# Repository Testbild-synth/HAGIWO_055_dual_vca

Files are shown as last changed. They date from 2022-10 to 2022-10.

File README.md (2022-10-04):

# Hagiwo Eurorack Dual Lin-Exp VCA
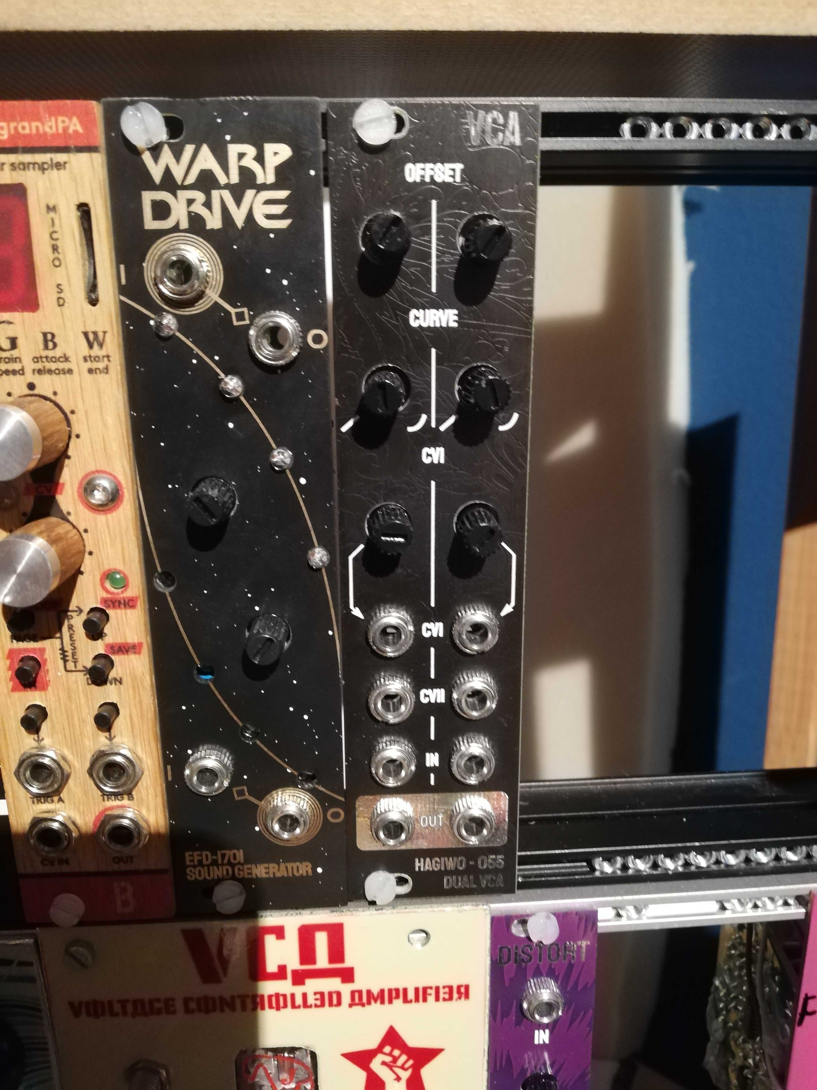
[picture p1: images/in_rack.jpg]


This project is a through hole PCB version the HAGIWO 055 dual veils-style VCA. I added a second CV in. 

## STATUS: CONFIRMED WORKING

## Hardware and PCB
this had to be 2 PCBs and 8HP (its hard to make it smaller without making it SMT), but I think i managed to get it very tidy.

You can find the schematic and BOM in the root folder. 
As mentioned, the module has one circuit PCB and one panel PCB. 

You can order them on any common PCB manufacturing service, I used JLCPCB. For the circuit PCB, standard settings should be fine.
For the panel, since it has copper exposed, make sure to choose a lead free surface finish (LeadFree HASL, ENIG) and/or spraypaint your panels so that you don't get lead on your hands.

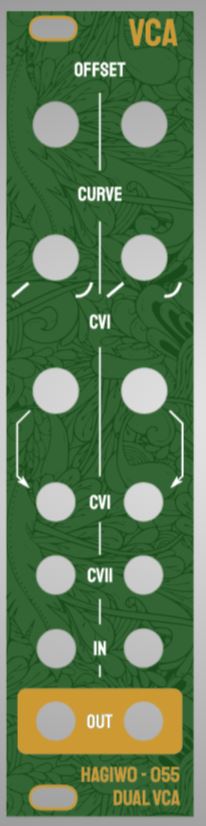
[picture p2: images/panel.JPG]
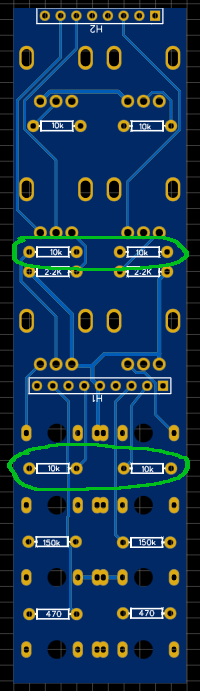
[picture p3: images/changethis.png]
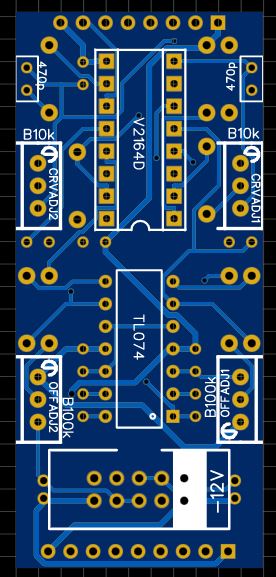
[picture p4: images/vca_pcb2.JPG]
  

Assembly is fairly straight forward, just use the componentent values.
The VCA is built for ~5V cv interval, if you with to use a bigger interval, try replacing the circled 10K resistors with different values.

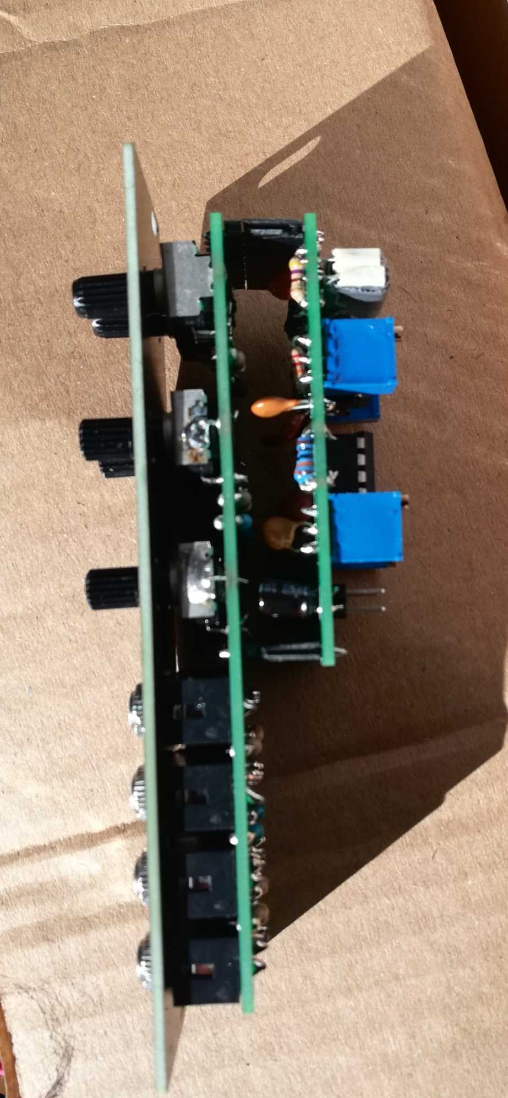
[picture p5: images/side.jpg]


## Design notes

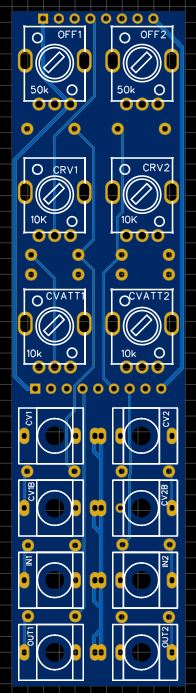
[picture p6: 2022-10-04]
images/vca_pcb1.JPG

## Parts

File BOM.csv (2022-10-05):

Name | Designator | Footprint | Quantity
100p capacitor | C1,C4,C6,C7 | RAD-0.1 | 4
100n capacitor | C2,C3,C10,C12 | RAD-0.1 | 4
470p capacitor | C5,C8 | RAD-0.1 | 2
10uF electrolytic capacitor | C9,C11 | CAP-TH_BD5.0-P2.00-D0.8-FD | 2
B10K Potentiometer R09 | CRV1,CRV2 | R09-5KΩ | 2
B10k Trimpot | CRVADJ1,CRVADJ2 | TRIMPOT-ELETROCURSOS-FOOTPRINT | 2
B100k Trimpot | OFFADJ1,OFFADJ2 | TRIMPOT-ELETROCURSOS-FOOTPRINT | 2
10k Potentiometer R09 | CVATT1,CVATT2 | R09-5KΩ | 2
B50k Potentiometer R09 | OFF1,OFF2 | R09-5KΩ | 2
2.54MM header (male and female) 1x9 | H1 | HDR-F-2.54_1X9 | 1
2.54MM header (male and female) 1x8 | H2 | HDR-F-2.54_1X8 | 1
CV1, CV2, CV1B, CV2B, IN1, IN2, OUT1, OUT2 | J1-J8 | THONKICONN_1 | 8
Eurorack power header/2x5 header | P1 | EURORACK SHROUDED POWER 10 PIN | 1
10k resistor | R1,R2,R3,R11,R12,R13 | R_AXIAL-0.3 | 6
2.2K resistor | R4,R14 | R_AXIAL-0.3 | 2
100k resistor | R5,R15 | R_AXIAL-0.3 | 2
33k resistor | R6,R16 | R_AXIAL-0.3 | 2
150k resistor | R7,R17 | R_AXIAL-0.3 | 2
470 resistor | R8,R9,R18,R19 | R_AXIAL-0.3 | 4
22k resistor | R10,R20 | R_AXIAL-0.3 | 2
7.5k resistor | R21 | R_AXIAL-0.3 | 1
TL074CJ | U1 | DIP14 | 1
V2164D | U2 | V2164D | 1

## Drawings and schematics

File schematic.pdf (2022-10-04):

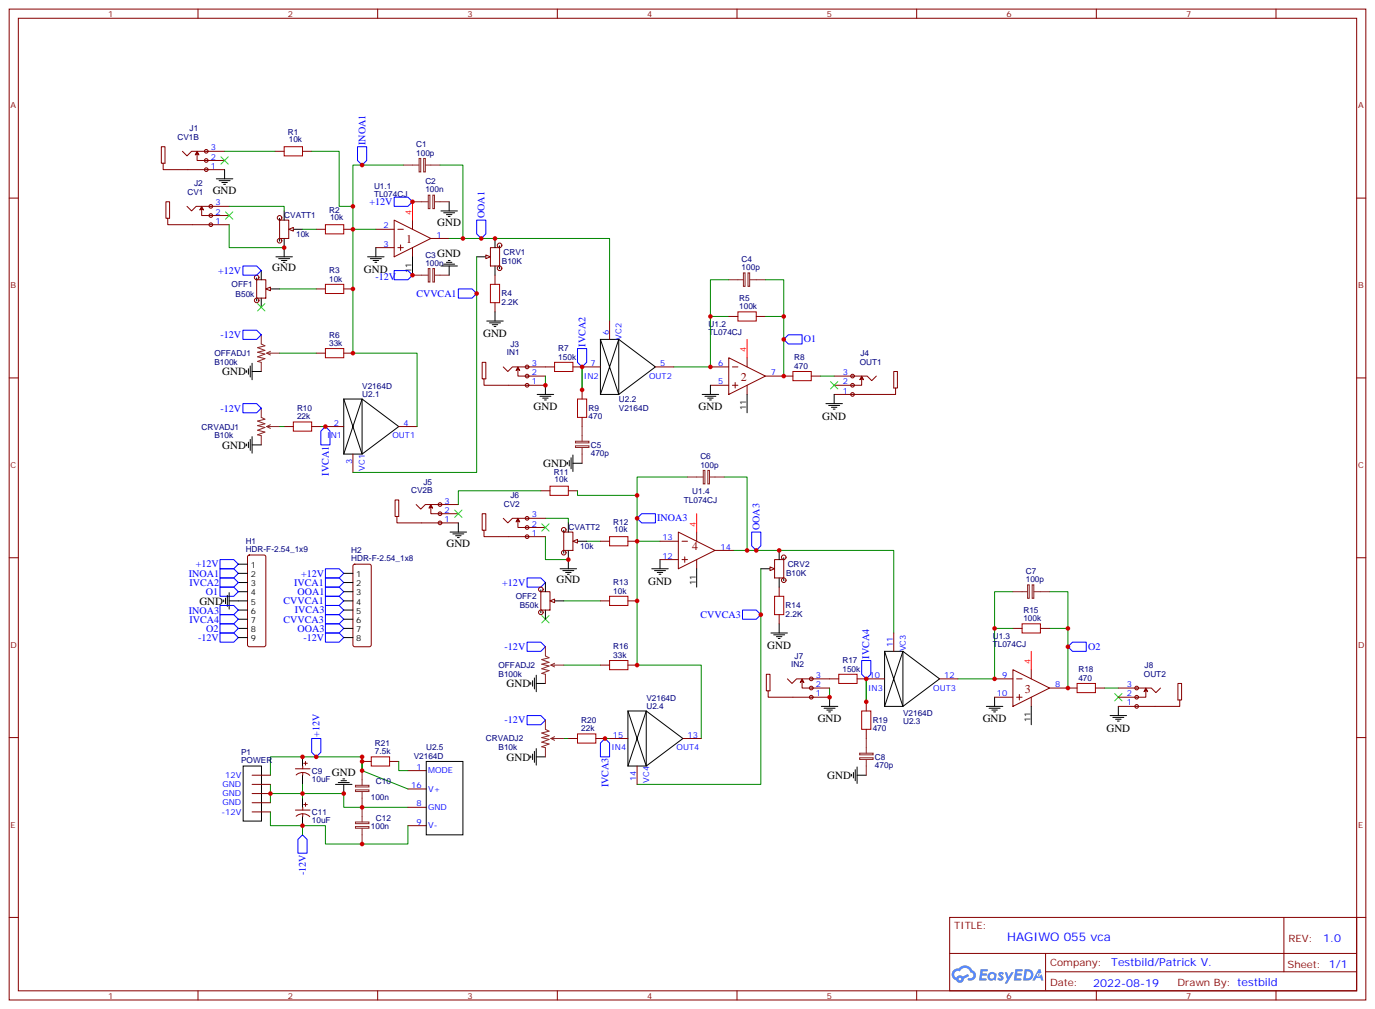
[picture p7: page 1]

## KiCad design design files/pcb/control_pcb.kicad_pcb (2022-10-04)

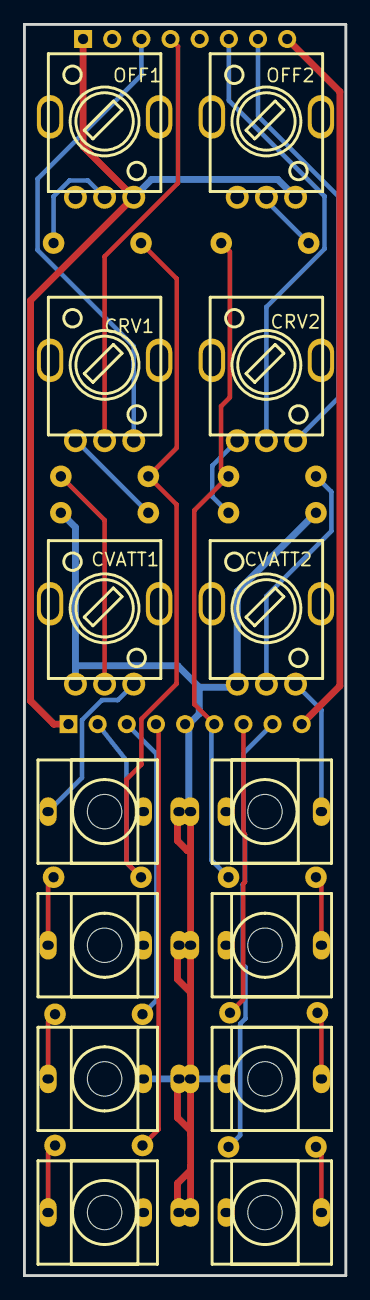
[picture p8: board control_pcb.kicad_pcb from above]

Board: 2 copper layers, 28.0 x 109.0 mm, 28 parts (0 on the bottom side), 27 nets.

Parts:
CRV1, CRV2: 10K; R09-5KΩ
CVATT1, CVATT2: 10k; R09-5KΩ
H1: HDR-F-2.54_1x9; HDR-F-2.54_1X9
H2: HDR-F-2.54_1x8; HDR-F-2.54_1X8
J1: CV1B; THONKICONN_1
J2: CV1; THONKICONN_1
J3: IN1; THONKICONN_1
J4: OUT1; THONKICONN_1
J5: CV2B; THONKICONN_1
J6: CV2; THONKICONN_1
J7: IN2; THONKICONN_1
J8: OUT2; THONKICONN_1
OFF1, OFF2: 50k; R09-5KΩ
R1, R2, R3, R11, R12, R13: 10k; R_AXIAL-0.3
R4, R14: 2.2K; R_AXIAL-0.3
R7, R17: 150k; R_AXIAL-0.3
R8, R18: 470; R_AXIAL-0.3

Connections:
+12V: H1.1, H2.1, OFF1.3, OFF2.3
-12V: H1.9, H2.8
CRV1_1: CRV1.1, R4.2
CVATT1_2: CVATT1.2, R2.1
CVATT2_3: CVATT2.3, J6.3
CVVCA1: CRV1.2, H2.4
CVVCA3: CRV2.2, H2.6
GND: CVATT1.1, CVATT2.1, H1.5, J1.1, J2.1, J3.1, J3.2, J4.1, J5.1, J6.1, J7.1, J7.2, J8.1, R4.1, R14.1
INOA1: H1.2, R1.2, R2.2, R3.2
INOA3: H1.6, R11.2, R12.2, R13.2
IVCA2: H1.3, R7.1
IVCA4: H1.7, R17.1
J1_3: J1.3, R1.1
J2_3: CVATT1.3, J2.3
J3_3: J3.3, R7.2
J5_3: J5.3, R11.1
J8_3: J8.3, R18.1
O1: H1.4, R8.2
O2: H1.8, R18.2
OFF1_2: OFF1.2, R3.1
OOA1: CRV1.3, H2.3
OOA3: CRV2.3, H2.7
R8_1: J4.3, R8.1
R12_1: CVATT2.2, R12.1
R13_1: OFF2.2, R13.1
R14_2: CRV2.1, R14.2
R17_2: J7.3, R17.2

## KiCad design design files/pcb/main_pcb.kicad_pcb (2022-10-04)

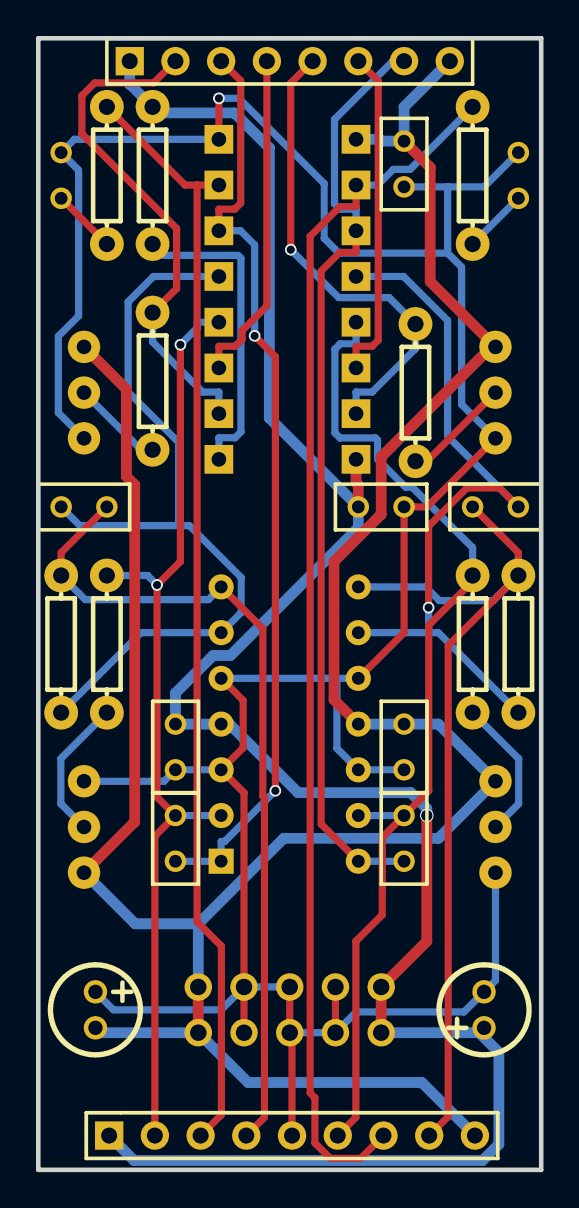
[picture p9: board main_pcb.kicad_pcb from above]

Board: 2 copper layers, 27.9 x 62.9 mm, 30 parts (0 on the bottom side), 24 nets.

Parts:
C1, C4, C6, C7: 100p; RAD-0.1
C2, C3, C10, C12: 100n; RAD-0.1
C5, C8: 470p; RAD-0.1
C9, C11: 10uF; CAP-TH_BD5.0-P2.00-D0.8-FD
CRVADJ1, CRVADJ2: B10k; TRIMPOT-ELETROCURSOS-FOOTPRINT
H1: HDR-F-2.54_1x9; HDR-F-2.54_1X9
H2: HDR-F-2.54_1x8; HDR-F-2.54_1X8
OFFADJ1, OFFADJ2: B100k; TRIMPOT-ELETROCURSOS-FOOTPRINT
P1: POWER; EURORACK SHROUDED POWER 10 PIN
R5, R15: 100k; R_AXIAL-0.3
R6, R16: 33k; R_AXIAL-0.3
R9, R19: 470; R_AXIAL-0.3
R10, R20: 22k; R_AXIAL-0.3
R21: 7.5k; R_AXIAL-0.3
U1: TL074; DIP14
U2: V2164D

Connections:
+12V: C2.2, C9.1, C10.1, H1.1, H2.1, P1.1, R21.1, U1.4, U2.16
-12V: C3.2, C11.2, C12.2, CRVADJ1.1, CRVADJ2.1, H1.9, H2.8, OFFADJ1.1, OFFADJ2.1, P1.5, U1.11, U2.9
C7_1: C7.1, R15.2, U1.9, U2.12
C8_1: C8.1, R19.2
CRVADJ1_2: CRVADJ1.2, R10.1
CVVCA1: H2.4, U2.3
CVVCA3: H2.6, U2.14
GND: C2.1, C3.1, C5.2, C8.2, C9.2, C10.2, C11.1, C12.1, CRVADJ1.3, CRVADJ2.3, H1.5, OFFADJ1.3, OFFADJ2.3, P1.2, P1.3, P1.4, U1.3, U1.5, U1.10, U1.12, U2.8
INOA1: C1.2, H1.2, R6.2, U1.2, U2.4
INOA3: C6.2, H1.6, R16.2, U1.13, U2.13
IVCA1: H2.2, R10.2, U2.2
IVCA2: H1.3, R9.1, U2.7
IVCA3: H2.5, R20.2, U2.15
IVCA4: H1.7, R19.1, U2.10
O1: C4.2, H1.4, R5.1, U1.7
O2: C7.2, H1.8, R15.1, U1.8
OFFADJ1_2: OFFADJ1.2, R6.1
OOA1: C1.1, H2.3, U1.1, U2.6
OOA3: C6.1, H2.7, U1.14, U2.11
R9_2: C5.1, R9.2
R16_1: OFFADJ2.2, R16.1
R20_1: CRVADJ2.2, R20.1
U1_6: C4.1, R5.2, U1.6, U2.5
U2_1: R21.2, U2.1
